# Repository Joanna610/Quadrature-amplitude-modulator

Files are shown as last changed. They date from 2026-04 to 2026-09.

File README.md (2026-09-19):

# Quadrature-amplitude-modulator

The goal of the project was to create two devices that would be wirelessly communicating with each other in simplex mode, using quadrature amplitude modulation at the 433 MHz band.

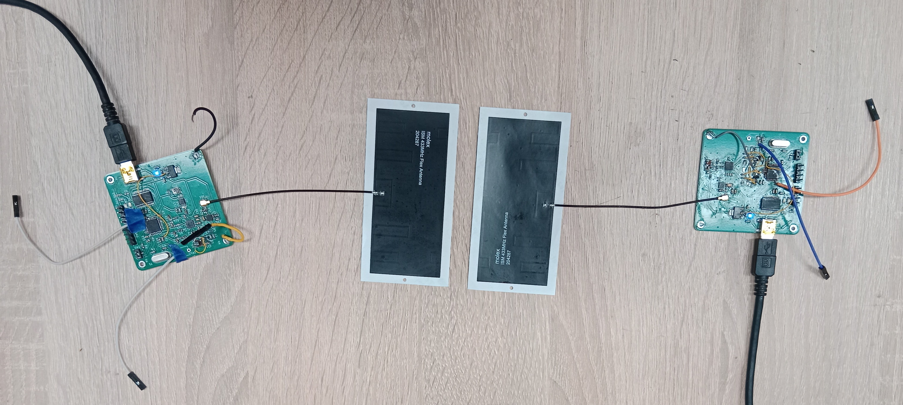
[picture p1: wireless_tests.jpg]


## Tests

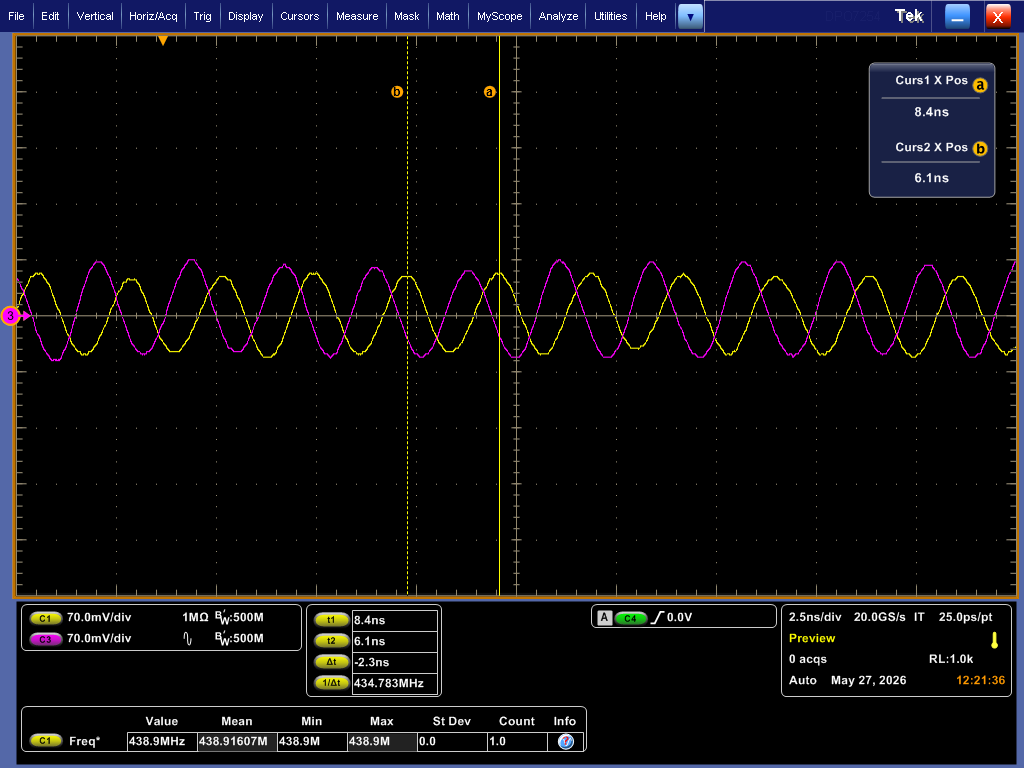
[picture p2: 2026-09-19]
receiver/measurements/band_pass/new_measurement/comparizon_band_pass_4.png

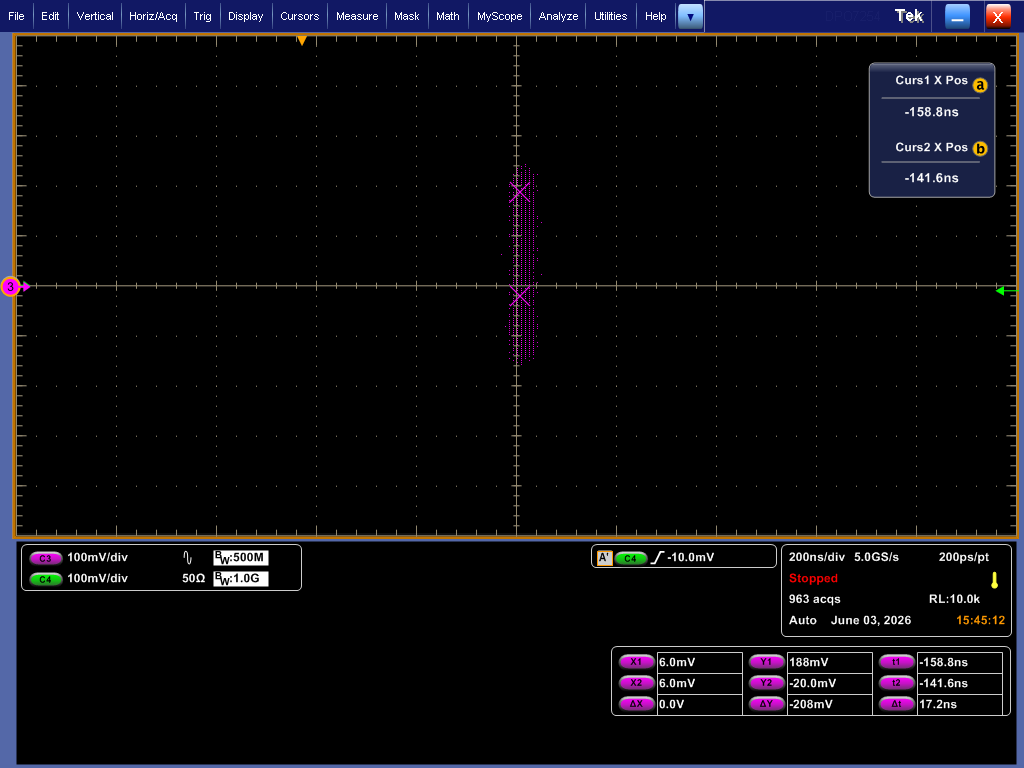
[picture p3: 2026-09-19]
receiver/measurements/mod_dem_connected_with_cabel/mod_dem_xy_differential_I_3.png

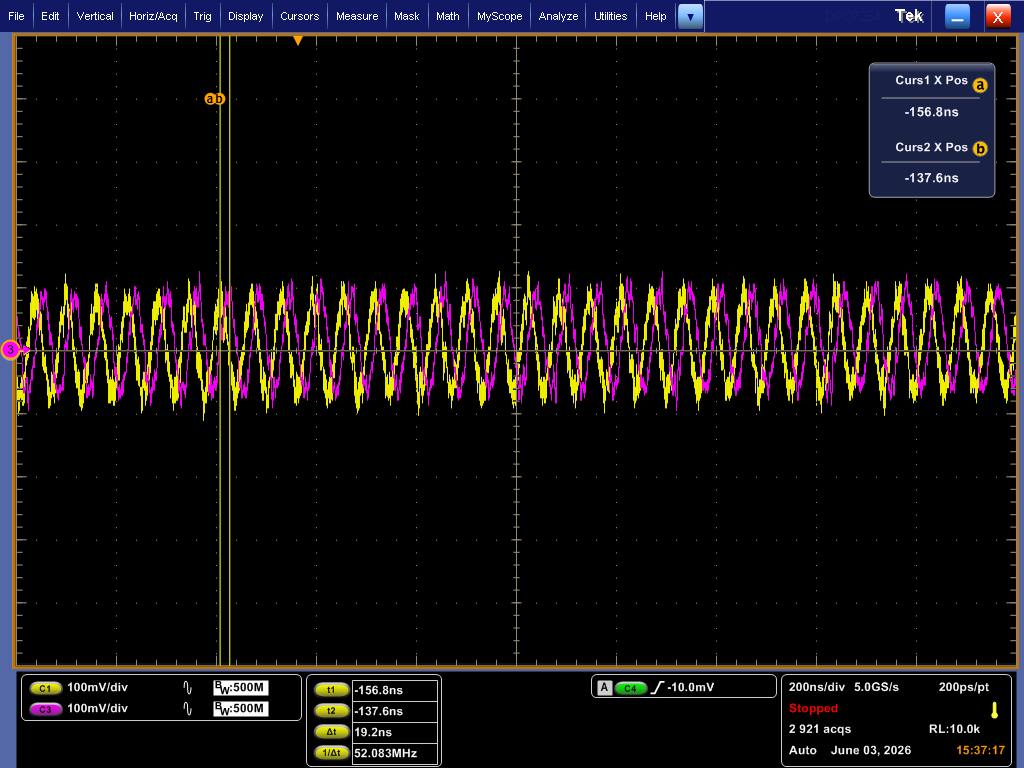
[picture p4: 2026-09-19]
receiver/measurements/mod_dem_connected_with_cabel/Mod_dem_phase_diff_3.png

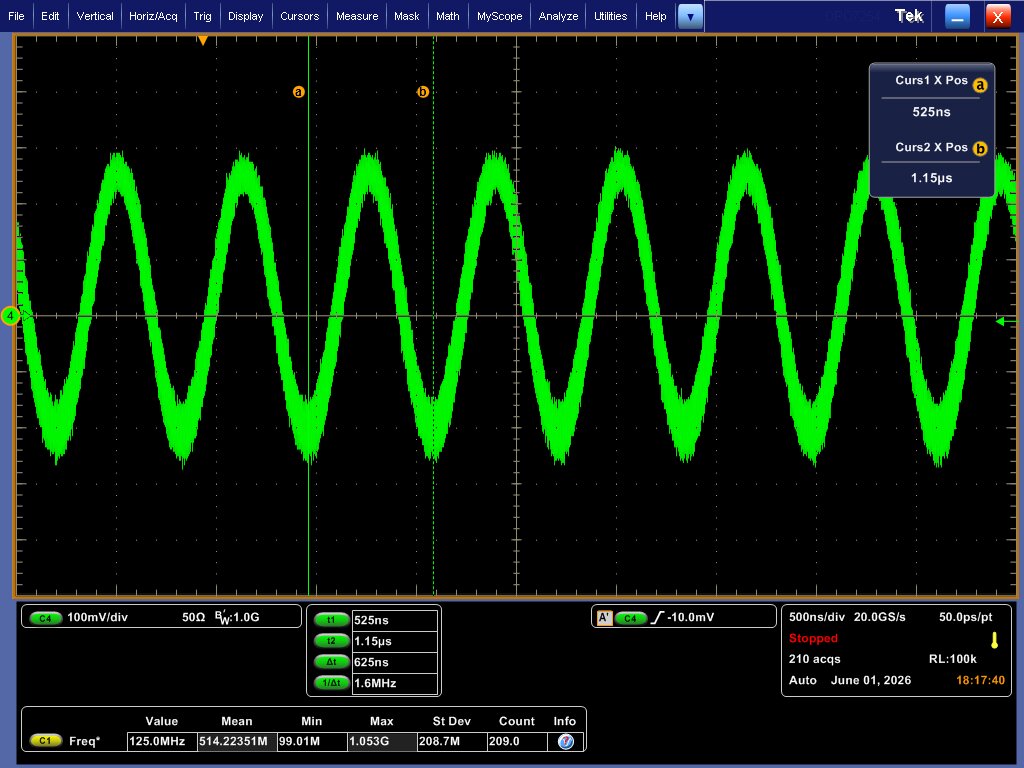
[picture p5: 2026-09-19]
receiver/measurements/all_system_together_433MHz/OUTPUT_jpg/433MHz_-12dBm_output_from_demodulator.jpg

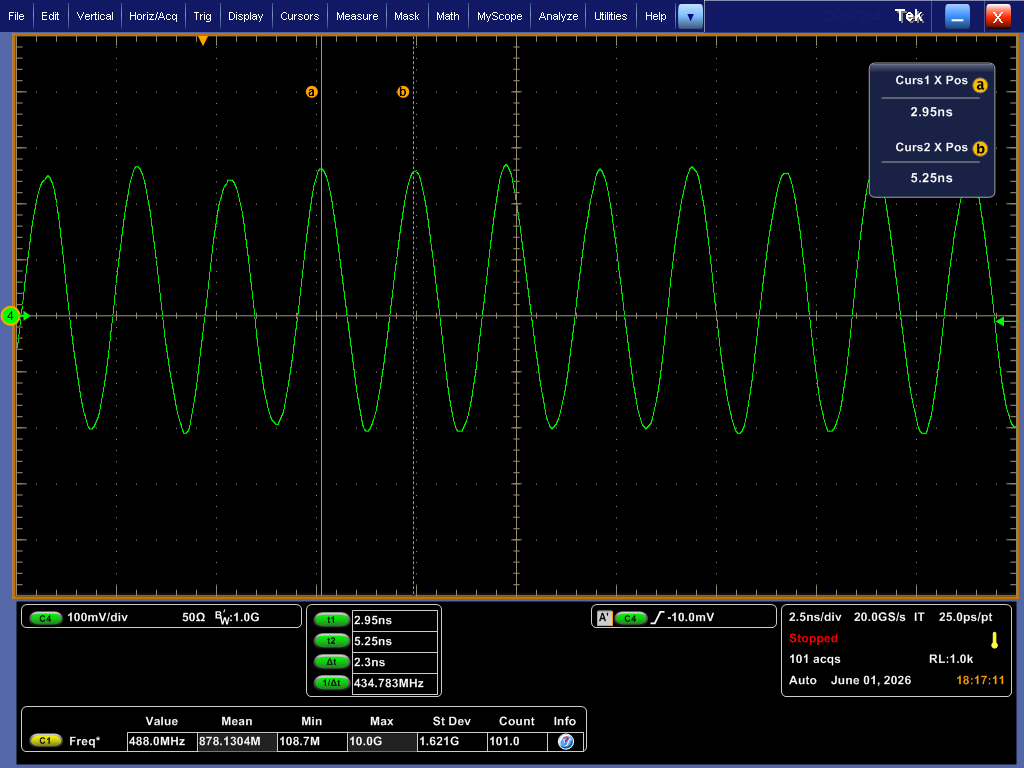
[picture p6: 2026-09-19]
receiver/measurements/all_system_together_433MHz/RF/433MHz_-12dBm_RF_from_transformator.png

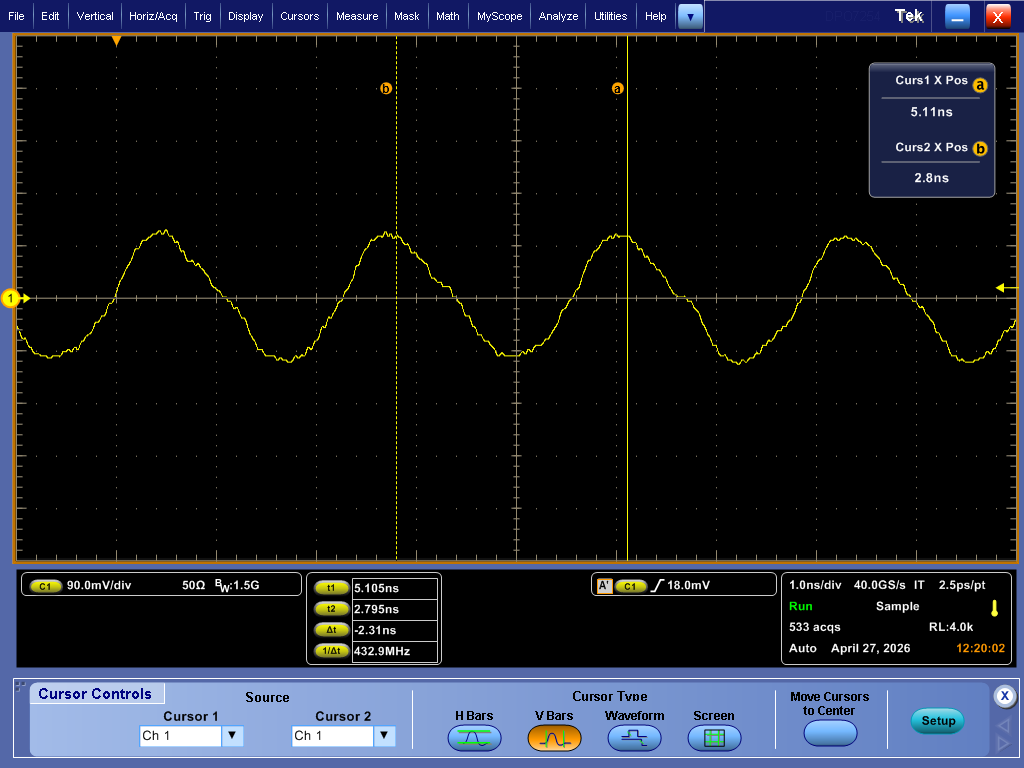
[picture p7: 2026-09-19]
transmiter/measurements/negative_2.png

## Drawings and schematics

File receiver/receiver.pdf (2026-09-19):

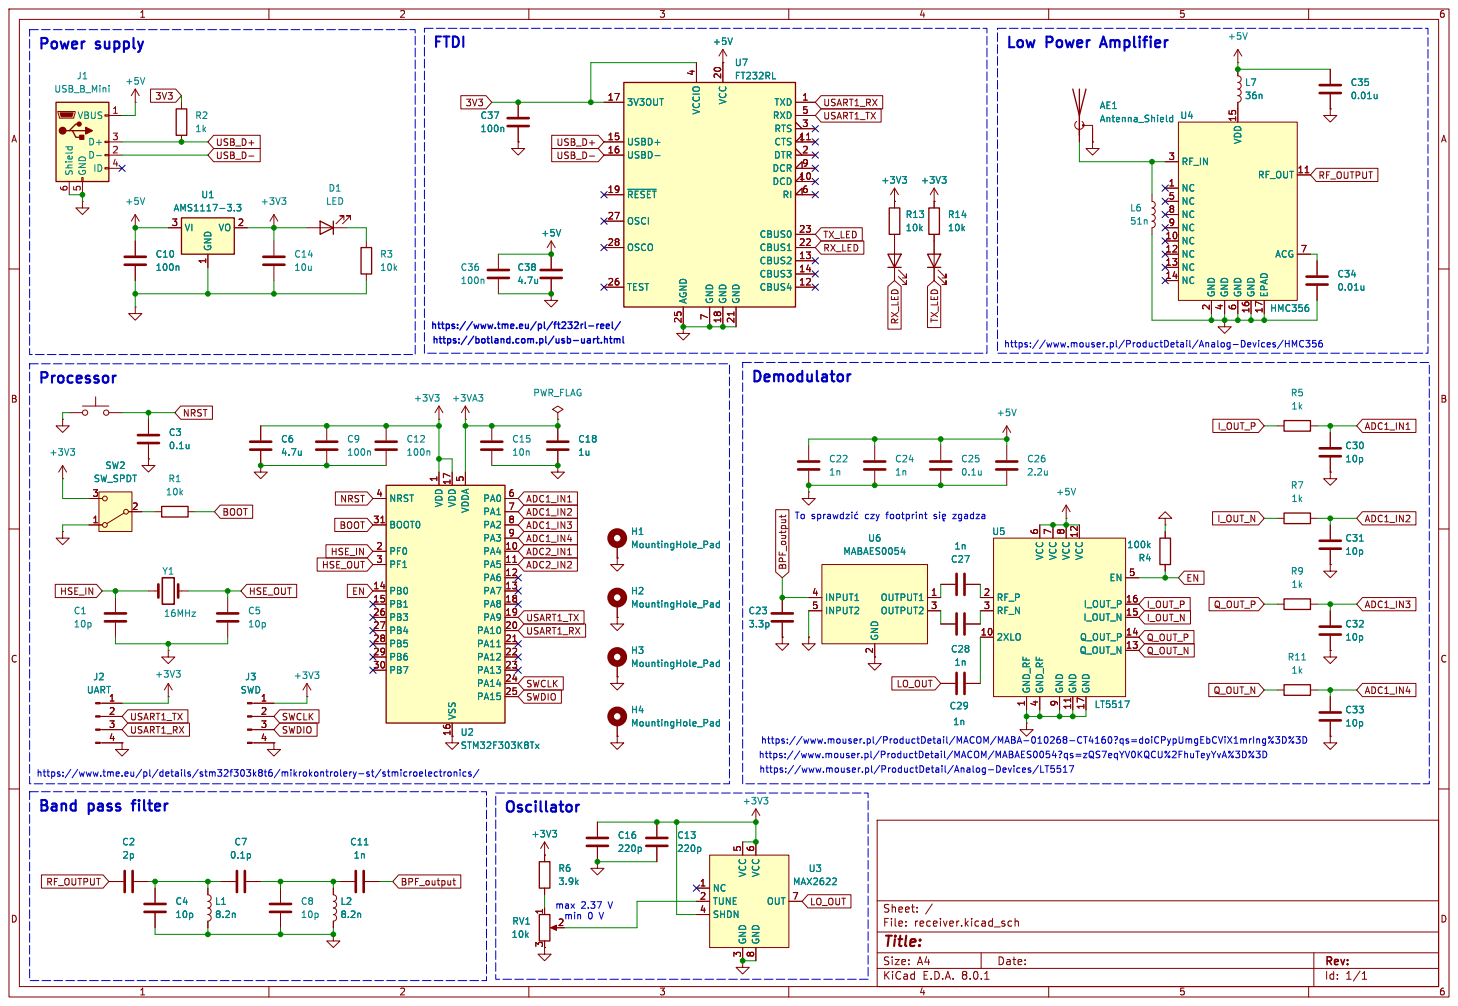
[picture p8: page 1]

7 DCR 9 U7 FT232RL +5V NC 1 NC 10 RF_OUT 11 NC 12 NC 13 NC 14 VDD 15 GND 16 EPAD 17 GND

7 DCR 9 +5V U4 HMC356 NC 1 NC 10 RF_OUT 11 NC 12 NC 13 NC 14 VDD 15 GND 16 EPAD 17 GND

10k U7 FT232RLTXD 1 DCD 10 CTS 11 CBUS4 12 CBUS2 13 CBUS3 14 USBD+ 15 USBD- 16

TXD 1 DCD 10 CTS 11 CBUS4 12 CBUS2 13 CBUS3 14 USBD+ 15 USBD- 16

https://www.tme.eu/pl/ft232rl-reel/ (https://www.tme.eu/pl/details/ft232rl/uklady-scalone-interfejs-usb/ftdi/ft232rl-reel/)
https://botland.com.pl/usb-uart.html (https://botland.com.pl/konwertery-usb-uart-rs232-rs485/4502-konwerter-usb-uart-ftdi-ft232rl-wtyk-usb-waveshare-6170-5904422374013.html)

1 PA4 10 PA5 11 PA6 12 PA7 13 PB0 14 PB1 15 VSS 16 VDD 17 PA8 18 PA9 19 PF0 2 PA10 20 PA11 21 PA12 22 PA13 23 PA14 24 PA15 25 PB3 26 PB4 27 PB5 28 PB6 29 PF1 3 PB7 30 BOOT0 31 NRST 4 VDDA
HSE_OUTSWCLK

https://www.mouser.pl/ProductDetail/MACOM/MABA-010268-CT4160?qs=doiCPypUmgEbCViX1mrIng%3D%3D
https://www.mouser.pl/ProductDetail/MACOM/MABAES0054?qs=zQS7eqYV0KQCU%2FhuTeyYvA%3D%3D

https://www.mouser.pl/ProductDetail/Analog-Devices/LT5517 https://www.tme.eu/pl/details/stm32f303k8t6/mikrokontrolery-st/stmicroelectronics/

Id: 1/1 Title: File: receiver.kicad_sch Sheet: /

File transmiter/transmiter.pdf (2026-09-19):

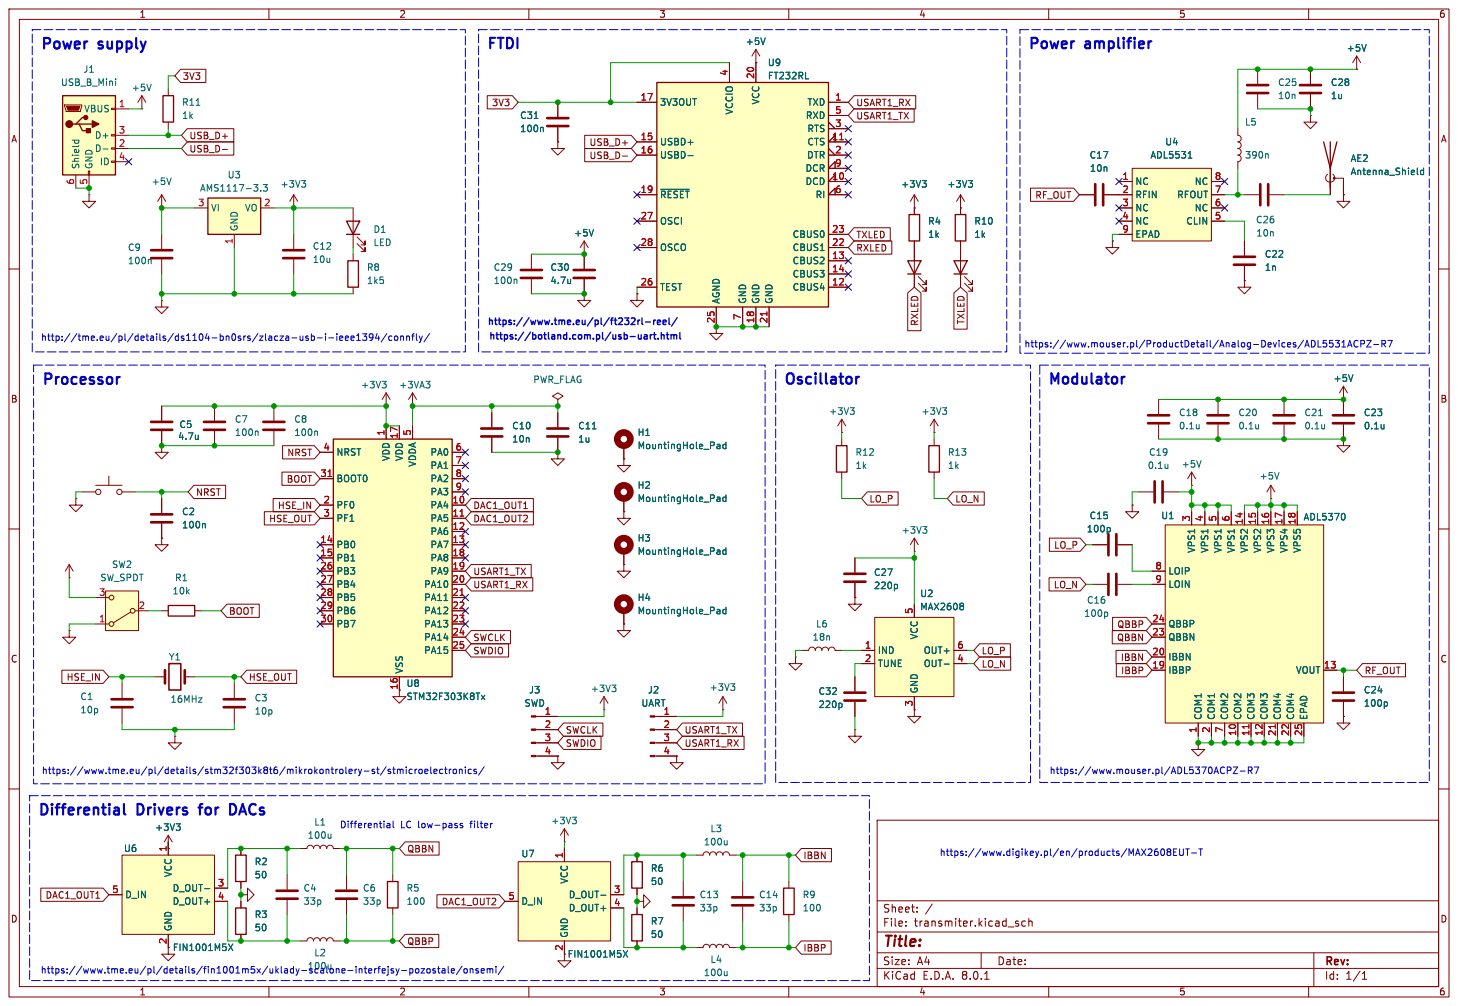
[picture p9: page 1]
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

http://tme.eu/pl/details/ds1104-bn0srs/zlacza-usb-i-ieee1394/connfly/

https://www.mouser.pl/ProductDetail/Analog-Devices/ADL5531ACPZ-R7

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

https://www.tme.eu/pl/details/stm32f303k8t6/mikrokontrolery-st/stmicroelectronics/

Id: 1/1 Title: File: transmiter.kicad_sch Sheet: / L1

https://www.digikey.pl/en/products/MAX2608EUT-T (https://www.digikey.pl/en/products/detail/analog-devices-inc-maxim-integrated/MAX2608EUT-T/1867439)

https://www.tme.eu/pl/details/fin1001m5x/uklady-scalone-interfejsy-pozostale/onsemi/

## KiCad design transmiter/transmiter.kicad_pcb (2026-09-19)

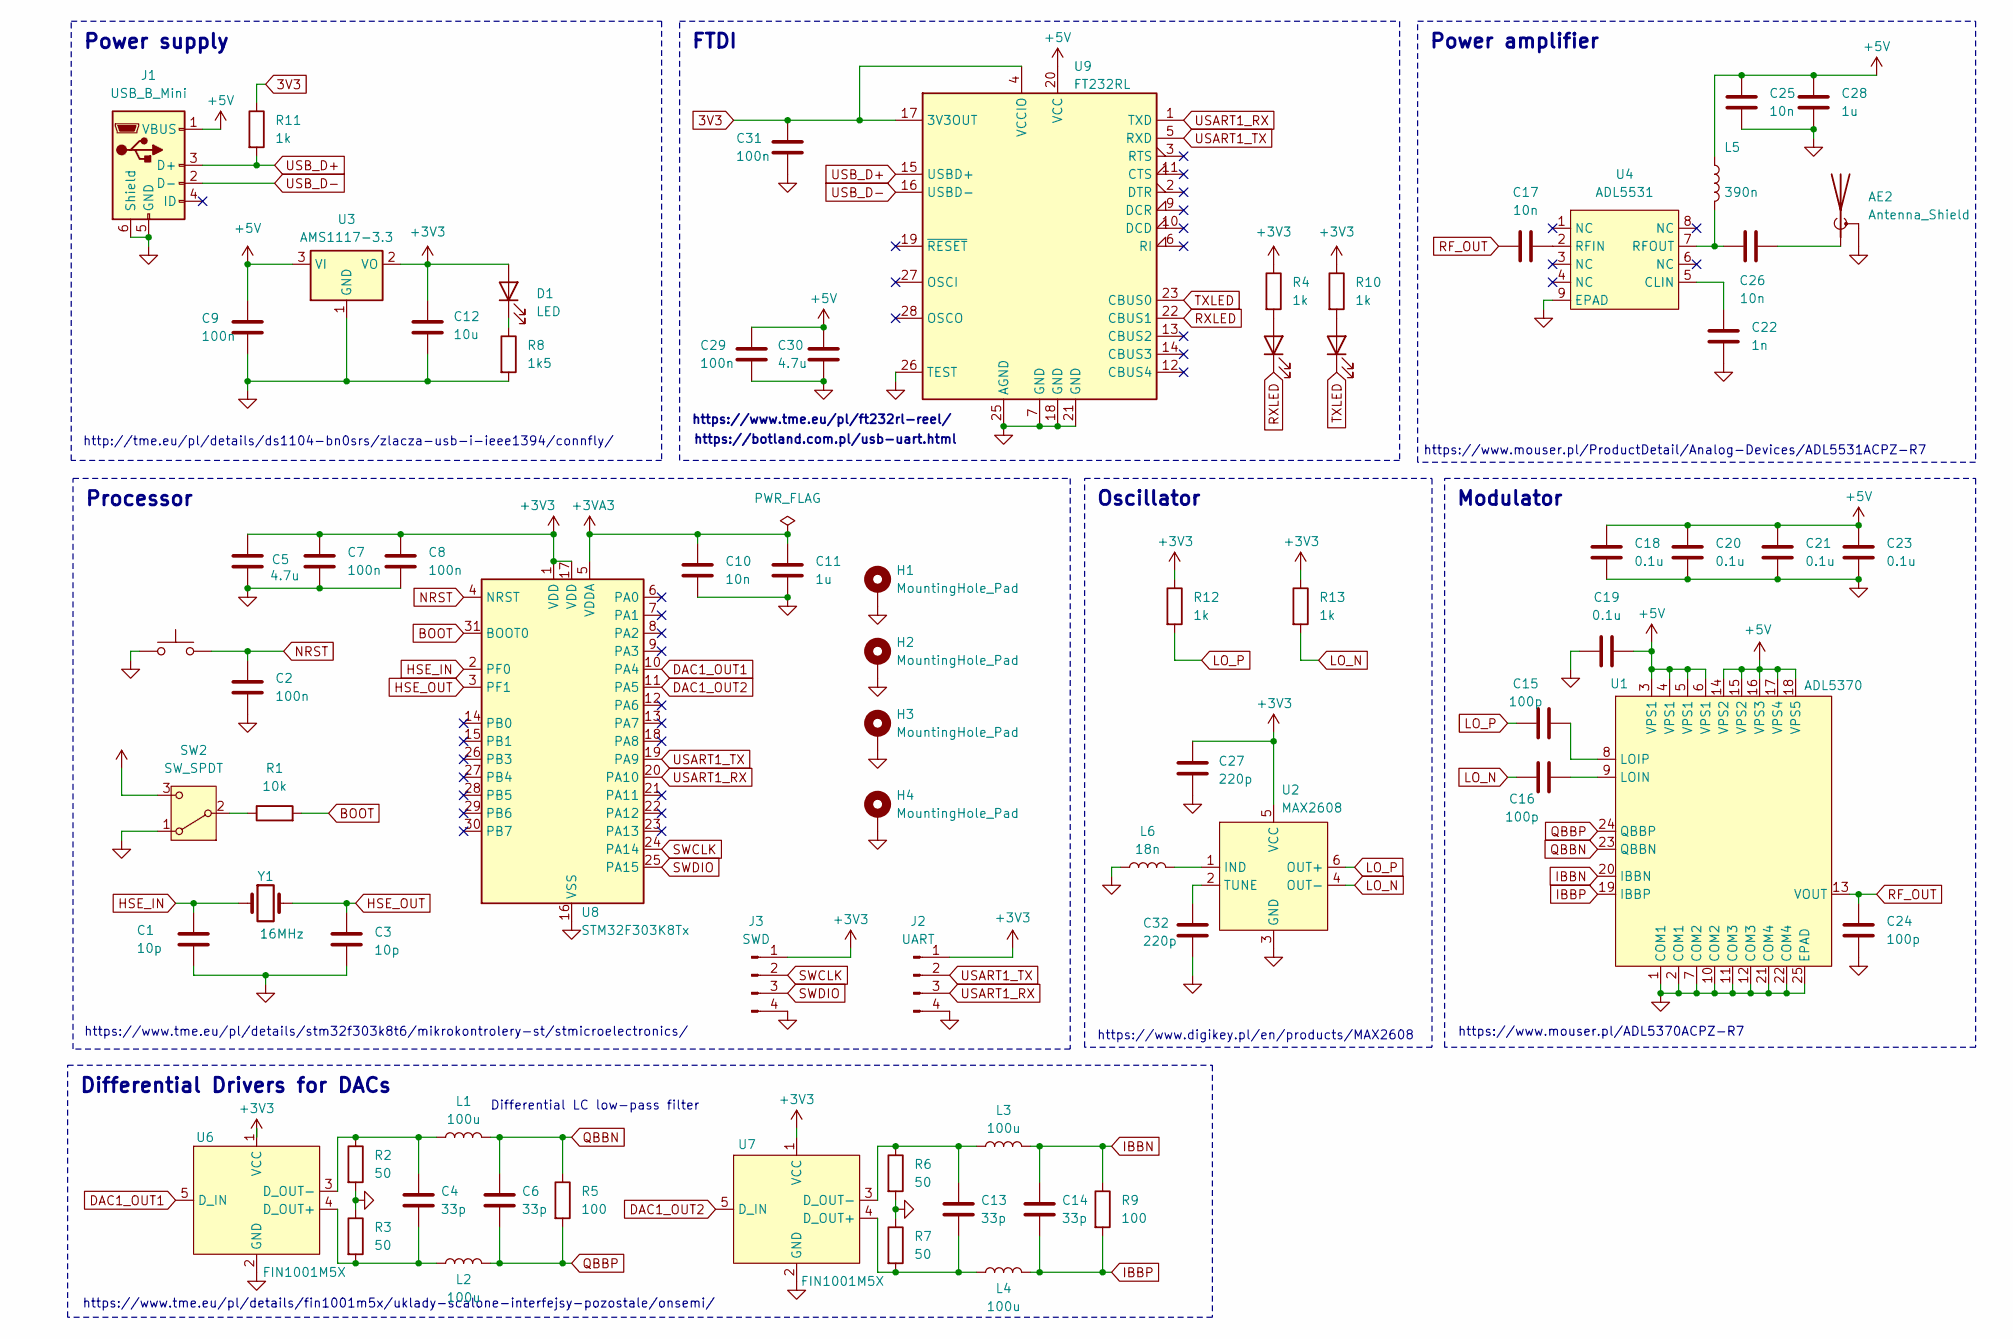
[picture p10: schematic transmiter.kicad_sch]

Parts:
AE2: Antenna_Shield; U.FL_Molex_MCRF_73412-0110_Vertical
C1, C3: 10p; C_0603_1608Metric_Pad1.08x0.95mm_HandSolder
C2, C7, C8, C9, C29, C31: 100n; C_0603_1608Metric_Pad1.08x0.95mm_HandSolder
C4, C6, C13, C14: 33p; C_0603_1608Metric_Pad1.08x0.95mm_HandSolder
C5, C30: 4.7u; C_0603_1608Metric_Pad1.08x0.95mm_HandSolder
C10, C25: 10n; C_0603_1608Metric_Pad1.08x0.95mm_HandSolder
C11, C28: 1u; C_0603_1608Metric_Pad1.08x0.95mm_HandSolder
C12: 10u; C_0603_1608Metric_Pad1.08x0.95mm_HandSolder
C15, C16, C24: 100p; C_0402_1005Metric_Pad0.74x0.62mm_HandSolder
C17, C26: 10n; C_0402_1005Metric_Pad0.74x0.62mm_HandSolder
C18, C19, C20, C21, C23: 0.1u; C_0402_1005Metric_Pad0.74x0.62mm_HandSolder
C22: 1n; C_0603_1608Metric_Pad1.08x0.95mm_HandSolder
C27, C32: 220p; C_0603_1608Metric_Pad1.08x0.95mm_HandSolder
D1, D2, D3: LED; LED_0805_2012Metric_Pad1.15x1.40mm_HandSolder
H1, H2, H3, H4: MountingHole_Pad; MountingHole_2.2mm_M2_DIN965_Pad
J1: USB_B_Mini; USB_Mini-B_Lumberg_2486_01_Horizontal
J2: UART; PinHeader_1x04_P2.54mm_Vertical
J3: SWD; PinHeader_1x04_P2.54mm_Vertical
L1, L2, L3, L4: 100u; L_1210_3225Metric_Pad1.42x2.65mm_HandSolder
L5: 390n; L_1008_2520Metric_Pad1.43x2.20mm_HandSolder
L6: 18n; L_0603_1608Metric_Pad1.05x0.95mm_HandSolder
R1: 10k; R_0603_1608Metric_Pad0.98x0.95mm_HandSolder
R2, R3, R6, R7: 50; R_0603_1608Metric_Pad0.98x0.95mm_HandSolder
R4, R10, R11, R12, R13: 1k; R_0603_1608Metric_Pad0.98x0.95mm_HandSolder
R5, R9: 100; R_0603_1608Metric_Pad0.98x0.95mm_HandSolder
R8: 1k5; R_0603_1608Metric_Pad0.98x0.95mm_HandSolder
SW1: SW_Push; PUSH
SW2: SW_SPDT; Nidec_Copal_CAS-120A
U1: ADL5370; LFCSP-24-1EP_4x4mm_P0.5mm_EP2.3x2.3mm
U2: MAX2608; SOT-23-6
U3: AMS1117-3.3; SOT-223-3_TabPin2
U4: ADL5531; LFCSP-8-1EP_3x3mm_P0.5mm_EP1.45x1.74mm
U6, U7: FIN1001M5X; SOT-23-5_HandSoldering
U8: STM32F303K8Tx; LQFP-32_7x7mm_P0.8mm
U9: FT232RL; SSOP-28_5.3x10.2mm_P0.65mm
Y1: 16MHz; Crystal_HC49-4H_Vertical

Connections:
3V3: C31.2, R11.1, U9.4 (VCCIO), U9.17 (3V3OUT)
+3V3: C5.1, C7.1, C8.1, C12.1, C27.2, D1.2 (A), J2.1, J3.1, R4.1, R10.1, R12.1, R13.1, SW2.3 (C), U2.5 (VCC), U3.2 (VO), U6.1 (VCC), U7.1 (VCC), U8.1 (VDD), U8.17 (VDD)
+3VA3: C10.1, C11.1, U8.5 (VDDA)
+5V: C9.2, C18.2, C19.1, C20.2, C21.2, C23.2, C25.1, C28.1, C29.2, C30.2, J1.1 (VBUS), L5.1, U1.3 (VPS1), U1.4 (VPS1), U1.5 (VPS1), U1.6 (VPS1), U1.14 (VPS2), U1.15 (VPS2), U1.16 (VPS3), U1.17 (VPS4), U1.18 (VPS5), U3.3 (VI), U9.20 (VCC)
BOOT: R1.2, U8.31 (BOOT0)
DAC1_OUT1: U6.5 (D_IN), U8.10 (PA4)
DAC1_OUT2: U7.5 (D_IN), U8.11 (PA5)
GND: AE2.2 (Shield), C1.2, C2.2, C3.2, C5.2, C7.2, C8.2, C9.1, C10.2, C11.2, C12.2, C18.1, C19.2, C20.1, C21.1, C22.2, C23.1, C24.2, C25.2, C27.1, C28.2, C29.1, C30.1, C31.1, C32.1, H1.1, H2.1, H3.1, H4.1, J1.5 (GND), J1.6 (Shield), J2.4, J3.4, L6.1, R2.2, R3.1, R6.2, R7.1, R8.2, SW1.1, SW2.1 (A), U1.1 (COM1), U1.2 (COM1), U1.7 (COM2), U1.10 (COM2), U1.11 (COM3), U1.12 (COM3), U1.21 (COM4), U1.22 (COM4), U1.25 (EPAD), U2.3 (GND), U3.1 (GND), U4.9 (EPAD), U6.2 (GND), U7.2 (GND), U8.16 (VSS), U8.32 (VSS), U9.7 (GND), U9.18 (GND), U9.21 (GND), U9.25 (AGND), U9.26 (TEST)
HSE_IN: C1.1, U8.2 (PF0), Y1.1
HSE_OUT: C3.1, U8.3 (PF1), Y1.2
IBBN: C14.1, L3.2, R9.1, U1.20 (IBBN)
IBBP: C14.2, L4.2, R9.2, U1.19 (IBBP)
LO_N: C16.1, R13.2, U2.4 (OUT-)
LO_P: C15.1, R12.2, U2.6 (OUT+)
NRST: C2.1, SW1.2, U8.4 (NRST)
unnamed: AE2.1 (A), C26.2
unnamed: D1.1 (K), R8.1
unnamed: D2.2 (A), R4.2
unnamed: D3.2 (A), R10.2
unnamed: R1.1, SW2.2 (B)
unnamed: C16.2, U1.9 (LOIN)
unnamed: C15.2, U1.8 (LOIP)
unnamed: L6.2, U2.1 (IND)
unnamed: C32.2, U2.2 (TUNE)
unnamed: C22.1, U4.5 (CLIN)
unnamed: C17.2, U4.2 (RFIN)
unnamed: C26.1, L5.2, U4.7 (RFOUT)
unnamed: C4.2, L2.1, R3.2, U6.4 (D_OUT+)
unnamed: C4.1, L1.1, R2.1, U6.3 (D_OUT-)
unnamed: C13.2, L4.1, R7.2, U7.4 (D_OUT+)
unnamed: C13.1, L3.1, R6.1, U7.3 (D_OUT-)
QBBN: C6.1, L1.2, R5.1, U1.23 (QBBN)
QBBP: C6.2, L2.2, R5.2, U1.24 (QBBP)
RF_OUT: C17.1, C24.1, U1.13 (VOUT)
RXLED: D2.1 (K), U9.22 (CBUS1)
SWCLK: J3.2, U8.24 (PA14)
SWDIO: J3.3, U8.25 (PA15)
TXLED: D3.1 (K), U9.23 (CBUS0)
USART1_RX: J2.3, U8.20 (PA10), U9.1 (TXD)
USART1_TX: J2.2, U8.19 (PA9), U9.5 (RXD)
USB_D+: J1.3 (D+), R11.2, U9.15 (USBD+)
USB_D-: J1.2 (D-), U9.16 (USBD-)

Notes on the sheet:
Oscillator
Power amplifier
Processor
Differential Drivers for DACs
FTDI
Power supply
Modulator
https://www.digikey.pl/en/products/MAX2608
Differential LC low-pass filter
https://www.tme.eu/pl/ft232rl-reel/
https://www.mouser.pl/ProductDetail/Analog-Devices/ADL5531ACPZ-R7
https://www.tme.eu/pl/details/fin1001m5x/uklady-scalone-interfejsy-pozostale/onsemi/
https://www.mouser.pl/ADL5370ACPZ-R7
https://botland.com.pl/usb-uart.html
https://www.tme.eu/pl/details/stm32f303k8t6/mikrokontrolery-st/stmicroelectronics/
http://tme.eu/pl/details/ds1104-bn0srs/zlacza-usb-i-ieee1394/connfly/

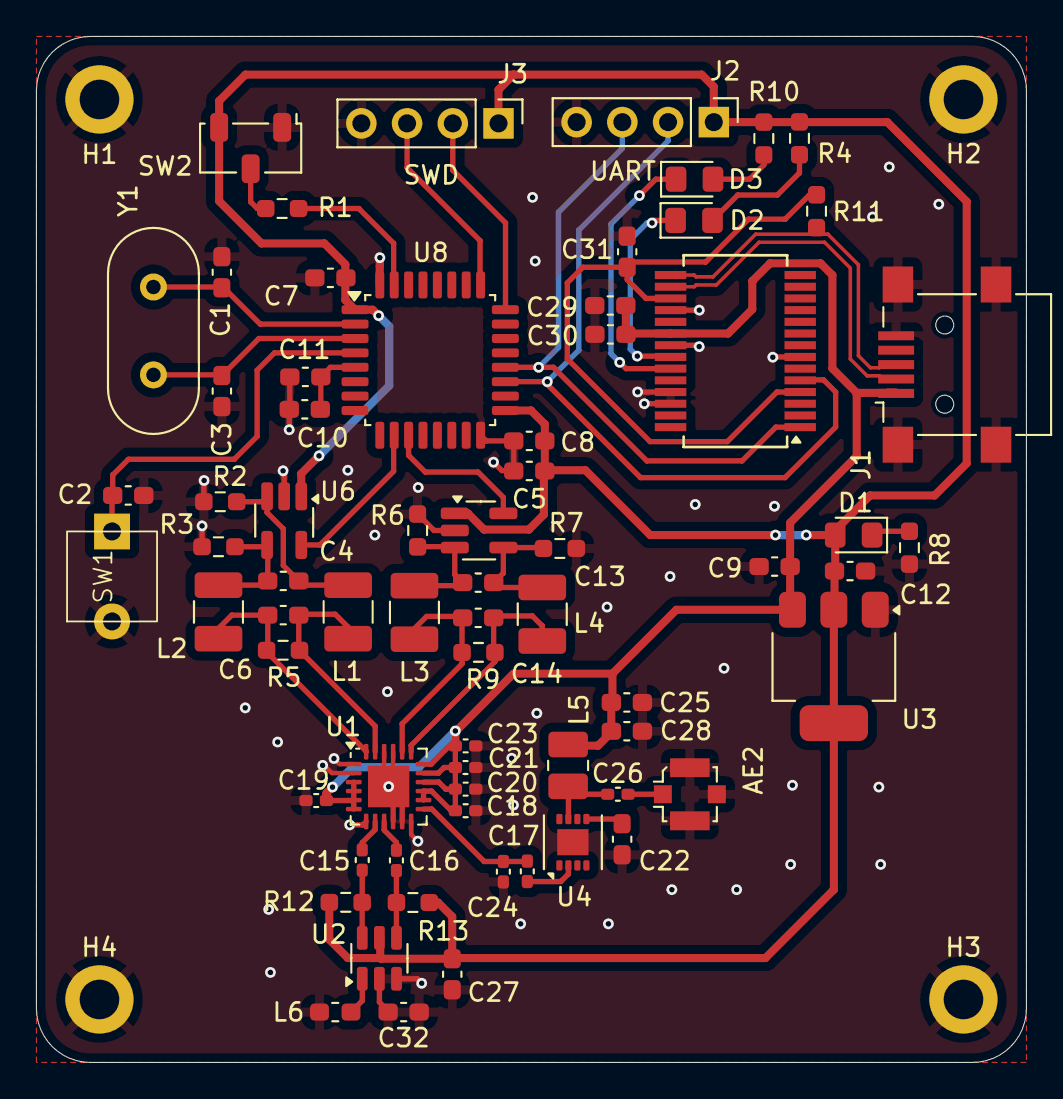
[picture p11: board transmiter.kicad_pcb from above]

Board: 2 copper layers, 55.0 x 57.0 mm, 73 parts (0 on the bottom side), 42 nets.

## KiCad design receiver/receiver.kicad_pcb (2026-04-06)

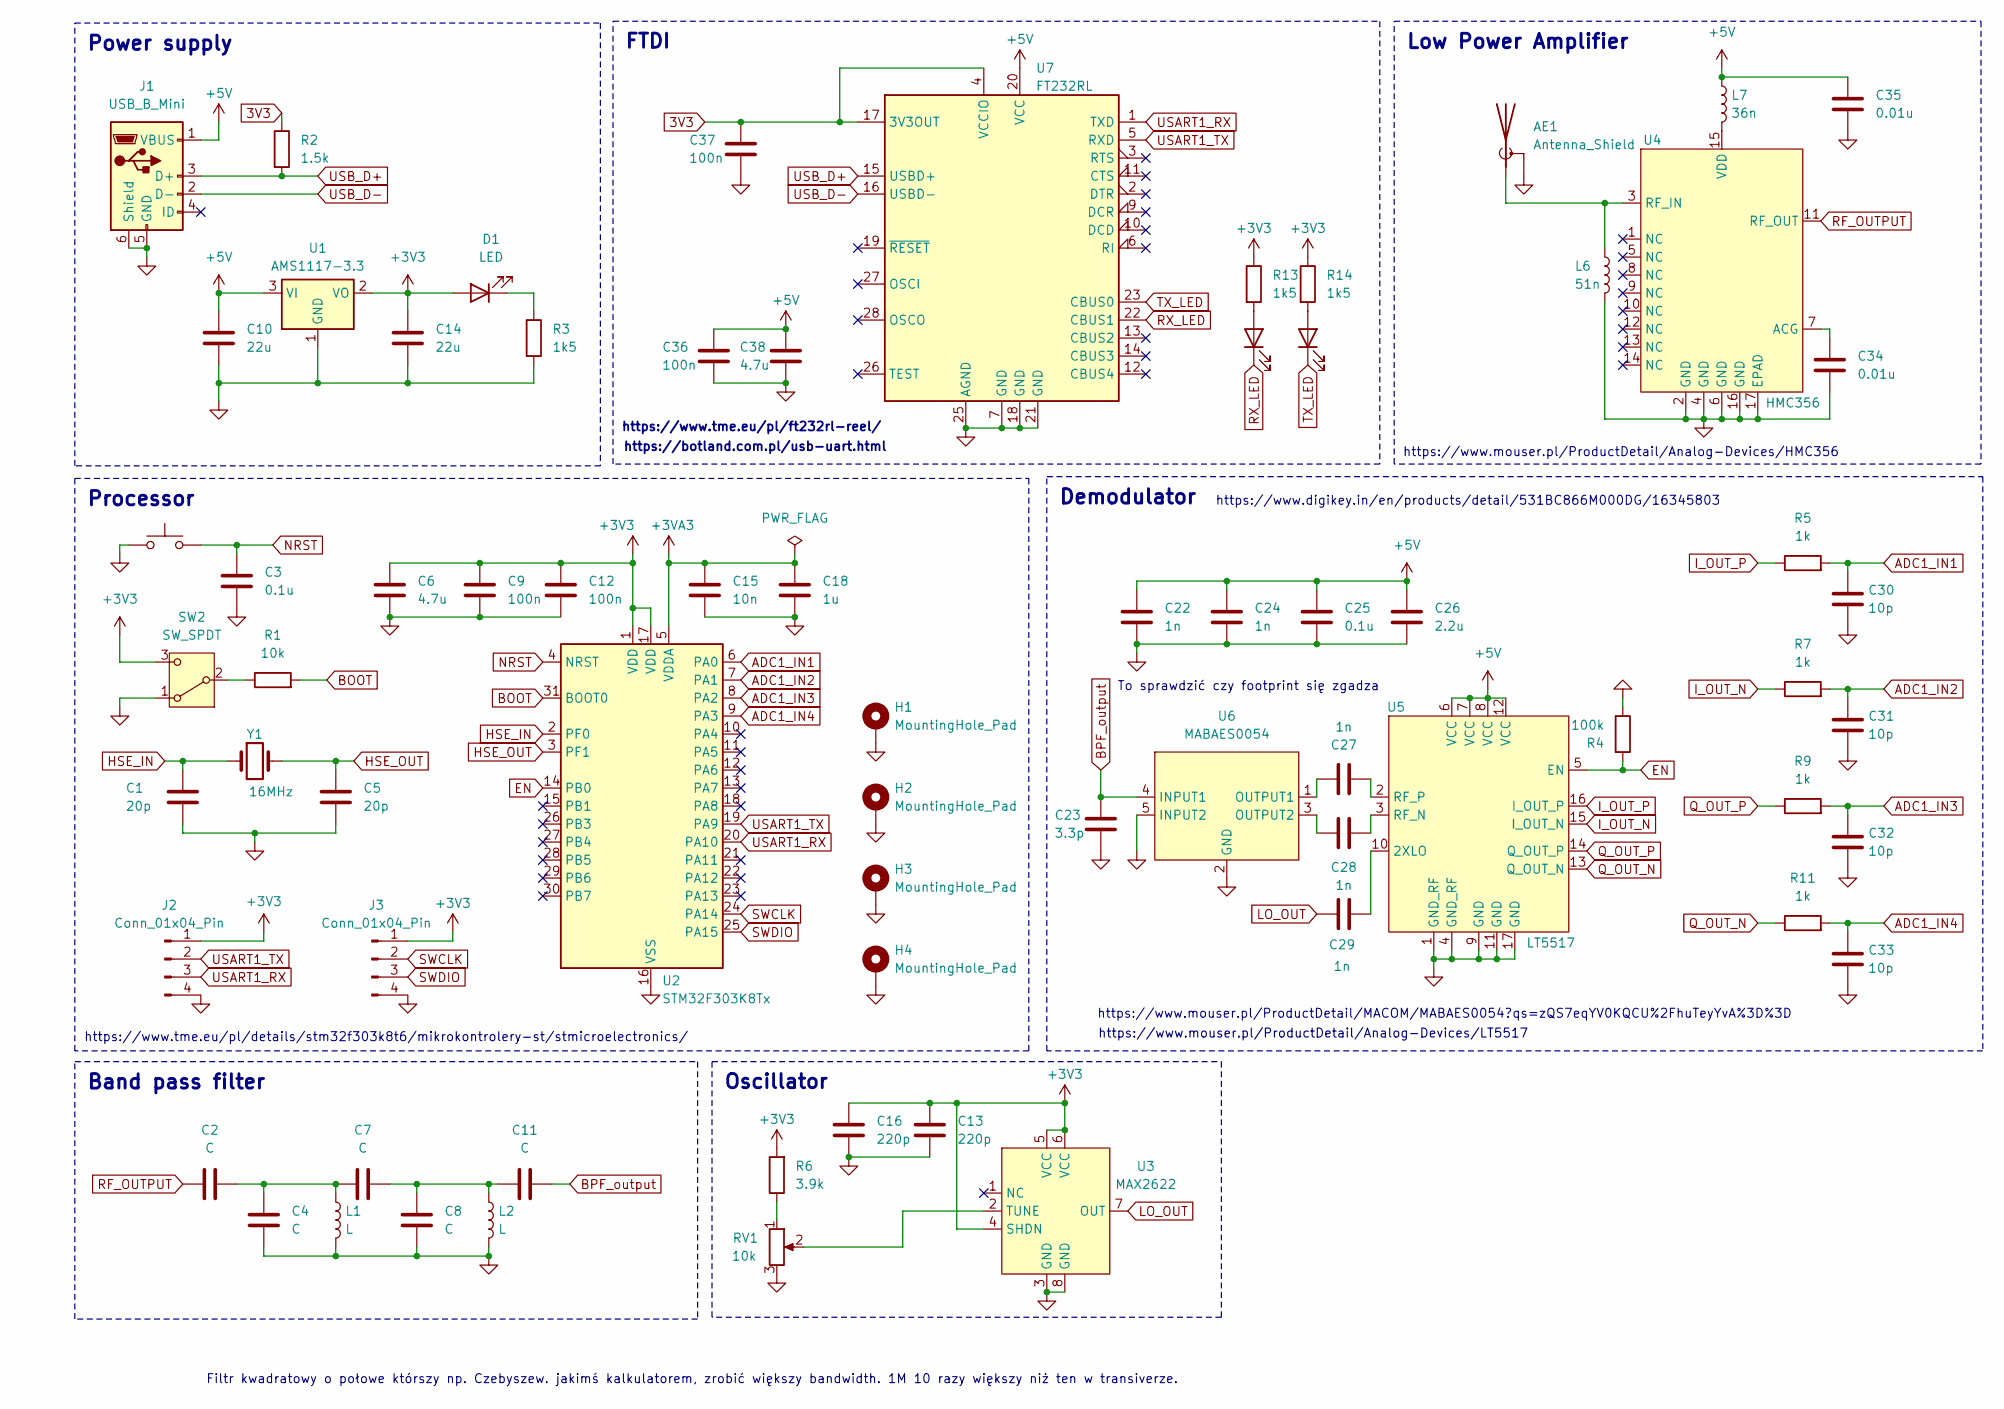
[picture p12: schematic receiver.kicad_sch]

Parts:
AE1: Antenna_Shield; U.FL_Molex_MCRF_73412-0110_Vertical
C1, C5: 20p; C_0603_1608Metric_Pad1.08x0.95mm_HandSolder
C2, C4, C7, C8, C11: C; C_0603_1608Metric_Pad1.08x0.95mm_HandSolder
C3, C25: 0.1u; C_0603_1608Metric_Pad1.08x0.95mm_HandSolder
C6, C38: 4.7u; C_0603_1608Metric_Pad1.08x0.95mm_HandSolder
C9, C12, C36, C37: 100n; C_0603_1608Metric_Pad1.08x0.95mm_HandSolder
C10, C14: 22u; C_0603_1608Metric_Pad1.08x0.95mm_HandSolder
C13, C16: 220p; C_0603_1608Metric_Pad1.08x0.95mm_HandSolder
C15: 10n; C_0603_1608Metric_Pad1.08x0.95mm_HandSolder
C18: 1u; C_0603_1608Metric_Pad1.08x0.95mm_HandSolder
C22, C24, C27, C28, C29: 1n; C_0603_1608Metric_Pad1.08x0.95mm_HandSolder
C23: 3.3p; C_0603_1608Metric_Pad1.08x0.95mm_HandSolder
C26: 2.2u; C_0603_1608Metric_Pad1.08x0.95mm_HandSolder
C30, C31, C32, C33: 10p; C_0805_2012Metric_Pad1.18x1.45mm_HandSolder
C34, C35: 0.01u; C_0603_1608Metric_Pad1.08x0.95mm_HandSolder
D1, D2, D3: LED; LED_0805_2012Metric_Pad1.15x1.40mm_HandSolder
H1, H2, H3, H4: MountingHole_Pad; MountingHole_2.2mm_M2_DIN965_Pad
J1: USB_B_Mini; USB_Mini-B_Lumberg_2486_01_Horizontal
J2, J3: Conn_01x04_Pin; PinHeader_1x04_P2.54mm_Vertical
L1, L2: L; L_0603_1608Metric_Pad1.05x0.95mm_HandSolder
L6: 51n; L_0603_1608Metric_Pad1.05x0.95mm_HandSolder
L7: 36n; L_0603_1608Metric_Pad1.05x0.95mm_HandSolder
R1: 10k; R_0603_1608Metric_Pad0.98x0.95mm_HandSolder
R2: 1.5k; R_0603_1608Metric_Pad0.98x0.95mm_HandSolder
R3, R13, R14: 1k5; R_0603_1608Metric_Pad0.98x0.95mm_HandSolder
R4: 100k; R_0603_1608Metric_Pad0.98x0.95mm_HandSolder
R5, R7, R9, R11: 1k; R_0603_1608Metric_Pad0.98x0.95mm_HandSolder
R6: 3.9k; R_0603_1608Metric_Pad0.98x0.95mm_HandSolder
RV1: 10k; Potentiometer_Bourns_TC33X_Vertical
SW1: SW_Push; PUSH
SW2: SW_SPDT; Nidec_Copal_CAS-120A
U1: AMS1117-3.3; SOT-223-3_TabPin2
U2: STM32F303K8Tx; LQFP-32_7x7mm_P0.8mm
U3: MAX2622; TSSOP-8_4.4x3mm_P0.65mm
U4: HMC356; QFN-16-1EP_3x3mm_P0.5mm_EP1.45x1.45mm
U5: LT5517; QFN-16-1EP_4x4mm_P0.65mm_EP2.1x2.1mm
U6: MABAES0054; Transformer_MACOM_SM-22
U7: FT232RL; SSOP-28_5.3x10.2mm_P0.65mm
Y1: 16MHz; Crystal_HC49-4H_Vertical

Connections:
3V3: C37.2, R2.1, U7.4 (VCCIO), U7.17 (3V3OUT)
+3V3: C6.1, C9.1, C12.1, C13.1, C14.1, C16.1, D1.2 (A), J2.1, J3.1, R6.2, R13.1, R14.1, SW2.3 (C), U1.2 (VO), U2.1 (VDD), U2.17 (VDD), U3.4 (SHDN), U3.5 (VCC), U3.6 (VCC)
+3VA3: C15.1, C18.1, U2.5 (VDDA)
+5V: C10.1, C22.1, C24.1, C25.1, C26.1, C35.1, C36.2, C38.2, J1.1 (VBUS), L7.1, U1.3 (VI), U5.6 (VCC), U5.7 (VCC), U5.8 (VCC), U5.12 (VCC), U7.20 (VCC)
ADC1_IN1: C30.1, R5.2, U2.6 (PA0)
ADC1_IN2: C31.1, R7.2, U2.7 (PA1)
ADC1_IN3: C32.1, R9.2, U2.8 (PA2)
ADC1_IN4: C33.1, R11.2, U2.9 (PA3)
BOOT: R1.2, U2.31 (BOOT0)
BPF_output: C11.2, C23.1, U6.4 (INPUT1)
EN: R4.2, U2.14 (PB0), U5.5 (EN)
GND: AE1.2 (Shield), C1.2, C3.2, C4.1, C5.2, C6.2, C8.1, C9.2, C10.2, C12.2, C13.2, C14.2, C15.2, C16.2, C18.2, C22.2, C23.2, C24.2, C25.2, C26.2, C30.2, C31.2, C32.2, C33.2, C34.2, C35.2, C36.1, C37.1, C38.1, H1.1, H2.1, H3.1, H4.1, J1.5 (GND), J1.6 (Shield), J2.4, J3.4, L1.2, L2.2, L6.2, R3.2, R4.1, RV1.3, SW1.1, SW2.1 (A), U1.1 (GND), U2.16 (VSS), U2.32 (VSS), U3.3 (GND), U3.8 (GND), U4.2 (GND), U4.4 (GND), U4.6 (GND), U4.16 (GND), U4.17 (EPAD), U5.1 (GND_RF), U5.4 (GND_RF), U5.9 (GND), U5.11 (GND), U5.17 (GND), U6.2 (GND), U6.5 (INPUT2), U7.7 (GND), U7.18 (GND), U7.21 (GND), U7.25 (AGND)
HSE_IN: C1.1, U2.2 (PF0), Y1.1
HSE_OUT: C5.1, U2.3 (PF1), Y1.2
I_OUT_N: R7.1, U5.15 (I_OUT_N)
I_OUT_P: R5.1, U5.16 (I_OUT_P)
LO_OUT: C29.2, U3.7 (OUT)
NRST: C3.1, SW1.2, U2.4 (NRST)
unnamed: AE1.1 (A), L6.1, U4.3 (RF_IN)
unnamed: C2.2, C4.2, C7.1, L1.1
unnamed: C7.2, C8.2, C11.1, L2.1
unnamed: D1.1 (K), R3.1
unnamed: D2.2 (A), R13.2
unnamed: D3.2 (A), R14.2
unnamed: R6.1, RV1.1
unnamed: R1.1, SW2.2 (B)
unnamed: RV1.2, U3.2 (TUNE)
unnamed: C34.1, U4.7 (ACG)
unnamed: L7.2, U4.15 (VDD)
unnamed: C29.1, U5.10 (2XLO)
unnamed: C28.1, U5.3 (RF_N)
unnamed: C27.2, U5.2 (RF_P)
unnamed: C27.1, U6.1 (OUTPUT1)
unnamed: C28.2, U6.3 (OUTPUT2)
Q_OUT_N: R11.1, U5.13 (Q_OUT_N)
Q_OUT_P: R9.1, U5.14 (Q_OUT_P)
RF_OUTPUT: C2.1, U4.11 (RF_OUT)
RX_LED: D2.1 (K), U7.22 (CBUS1)
SWCLK: J3.2, U2.24 (PA14)
SWDIO: J3.3, U2.25 (PA15)
TX_LED: D3.1 (K), U7.23 (CBUS0)
USART1_RX: J2.3, U2.20 (PA10), U7.1 (TXD)
USART1_TX: J2.2, U2.19 (PA9), U7.5 (RXD)
USB_D+: J1.3 (D+), R2.2, U7.15 (USBD+)
USB_D-: J1.2 (D-), U7.16 (USBD-)

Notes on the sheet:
Oscillator
Low Power Amplifier
Power supply
FTDI
Demodulator
Band pass filter
Processor
https://www.digikey.in/en/products/detail/531BC866M000DG/16345803
https://www.mouser.pl/ProductDetail/Analog-Devices/HMC356
To sprawdzić czy footprint się zgadza
https://www.mouser.pl/ProductDetail/Analog-Devices/LT5517
https://botland.com.pl/usb-uart.html
https://www.tme.eu/pl/ft232rl-reel/
https://www.tme.eu/pl/details/stm32f303k8t6/mikrokontrolery-st/stmicroelectronics/
Filtr kwadratowy o połowe którszy np. Czebyszew. jakimś kalkulatorem, zrobić większy bandwidth. 1M 10 razy większy niż ten w transiverze.
https://www.mouser.pl/ProductDetail/MACOM/MABAES0054?qs=zQS7eqYV0KQCU%2FhuTeyYvA%3D%3D

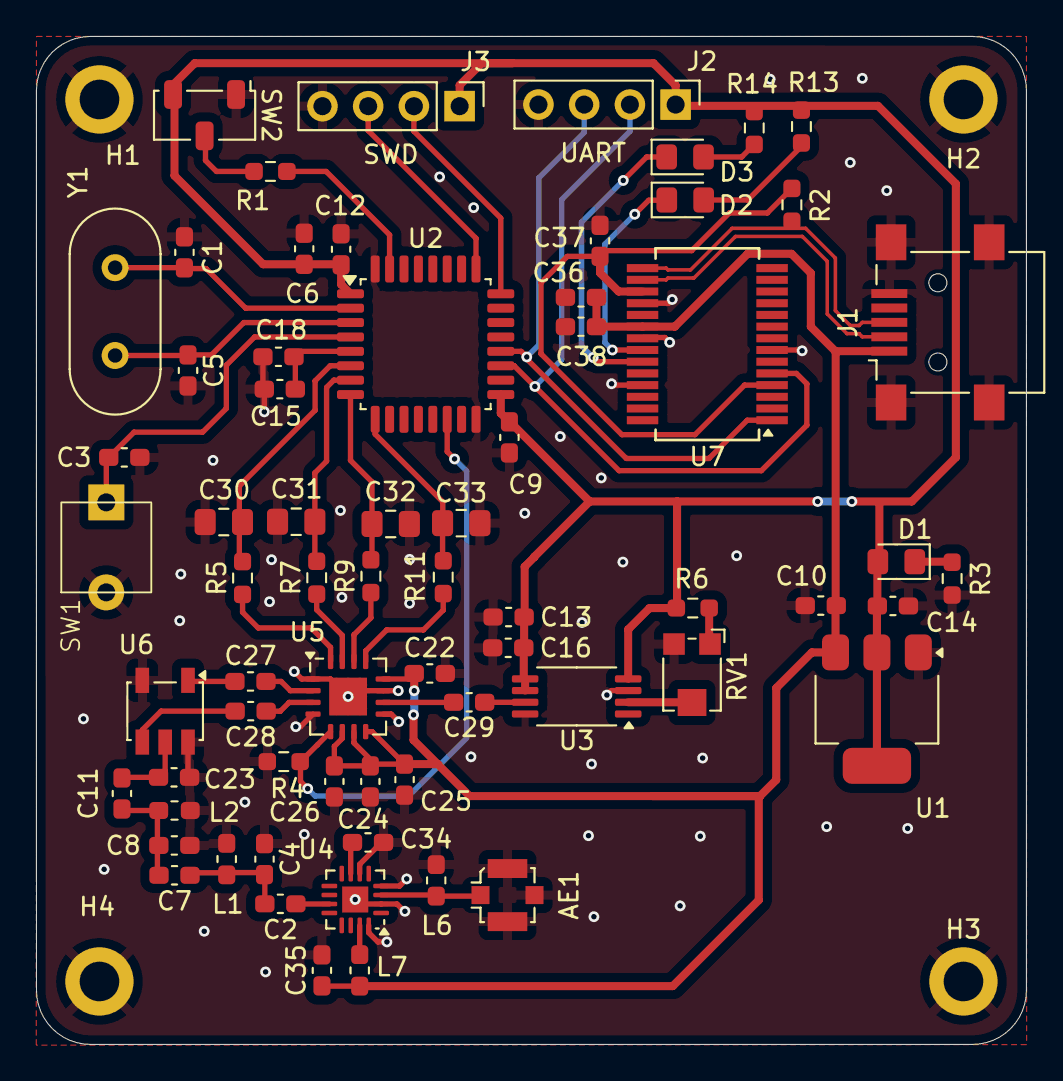
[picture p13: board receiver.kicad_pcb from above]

Board: 2 copper layers, 55.0 x 56.0 mm, 71 parts (0 on the bottom side), 45 nets.

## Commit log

2026-03-07 KiCad schematic design
    [receiver.kicad_pcb, receiver.kicad_sch, transmiter.kicad_pcb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]
2026-03-20 First stage of PCB design
    [receiver.kicad_pcb, receiver.kicad_sch, transmiter.kicad_pcb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]
2026-03-29 Finished PCB design
    [receiver.kicad_pcb, receiver.kicad_sch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]
2026-04-06 First design of sended PCBs
    [receiver-B_Cu.gbl, receiver-B_Mask.gbs, receiver-B_Paste.gbp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]
2026-04-19 Correction to PCBs
    [receiver.kicad_sch, transmiter.kicad_sch]
2026-09-19 Final version
    [receiver.kicad_sch, transmiter.kicad_pcb, transmiter.kicad_sch]
